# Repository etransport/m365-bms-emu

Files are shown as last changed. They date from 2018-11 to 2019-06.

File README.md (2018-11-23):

# m365-bms-emu
Xiaomi M365 BMS emulator

Main goals of this project: <br>
1 - Emulate communication sequence between ESC and BMS.<br>
2 - Ensure stability and safity over variety of firmwares.<br>

Documentation used in development:<br>
1 - https://electro.club/forum/zamena_yacheek_akb_na_Xiaomi_Mijia_Scooter<br>
2 - https://electro.club/forum/printsipialnaya_shema_drayvera_mk_Xiaomi_M365<br>
3 - https://electro.club/forum/podklyuchenie_alternativnogo_akkumulyatora_k_syaokatu<br>

Hardware used in development:<br>
1 - AVR Attiny CPUS 13/45/85/2313/412/816 in order to determine best price/performance ratio.<br>
2 - AVR Atmega dev boards nano/mini pro/micro pro etc<br>
3 - Seleae logic analyzer <br>

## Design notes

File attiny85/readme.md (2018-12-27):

## ATTINY85 version

**Features:**
- Full duplex communication
- Minimal amount of components needed
- Battery voltage indication
- Auto CRC calculation 
- Customizable battery serial
- ESC overvoltage protection 

**Known bugs:**
- Inaccurate remaining percentage calculation 

Feel free to use or modify as you wish

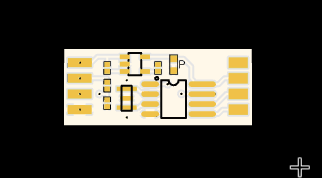
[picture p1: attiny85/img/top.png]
Top view

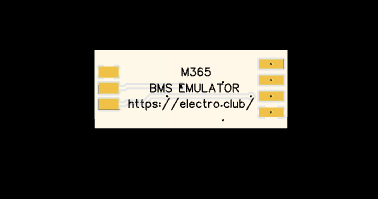
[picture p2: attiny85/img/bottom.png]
Bottom view


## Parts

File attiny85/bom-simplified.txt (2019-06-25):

BOM [M365 BMS EMULATOR V1.1]:
1x B04B-PASK-1 jst header
1x PAP-03V-S jst header
1x PAP-04V-S jst header
7x SPHD-002 copper inserts
1X PCB (see grbl folder)
1x 0402 10Mom 1% resistor
1x 0402 750Kom 1% resistor
1x 0402 10Kom 1% resistor
1x 0603 22uF  5% ceramic capacitor
1x CSTCE 16MHZ ceramic resonator 
1x Attiny85-20SU wsop8 mcu
1x LP2992AIM5 sot23-5 3.3v 250mA low noise regulator

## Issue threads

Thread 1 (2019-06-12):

Connection & pinout

NetBUG, 2019-06-12:
Hi @truesurge!
Thanks for great work on reverse engineering and redesigning the BMS!

Can I ask you to either submit the principal circuit diagram, or to add a PCB image with pinout?
As far as I understand, there are 4 connection pins (3 pins towards main M365 controller and a wire to B10/+42V of the battery), and 6 ICSP pins

I am working on the same circuit for Tiny45 + 1206 elemenes, and promise to publish it ASAP.

truesurge, 2019-06-12:
Hey, @NetBUG.
To start off - I did not redesign bms.
This emulator supposed to work with another bms (cheap/generic chinese), providing m365's main controller with all the info it needs. Basically, it gives user the ability to use another bms, emulator is not a standalone device

Main idea behind the device - read current battery voltage ,  calculate some approximate stats (veeeery inaccurate, as we cant get current consumption) an answer to m365 with correct data.

You can measure battery voltage using BLE connector (4pin), as the power button is connected to B+ through it.
To communicate with esc you need only 2 wires , rx/tx are located on the left side of 3pin.

I will include some pics a bit later

NetBUG, 2019-06-12:
Thanks! I know this is not a BMS, this is a stub replying to Ninebot bus telling battery state, mostly mocking it.

Will wait for pics, will try to find controller pinout

truesurge, 2019-06-23:
> Thanks! I know this is not a BMS, this is a stub replying to Ninebot bus telling battery state, mostly mocking it.
>
> Will wait for pics, will try to find controller pinout

Added image of assembled board in img folder

NetBUG, 2019-06-24:
Awesome! Got your point, I forgot initially about 3.3V LDO.
Here is a circuit I've made based on your design, but the yours is much nicer.
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

truesurge, 2019-06-25:
Yep, looks legit

bugster44, 2019-12-12:
What  values are C1, C2 and C3?

al3x-huang, 2022-06-14:
> Main idea behind the device - read current battery voltage , calculate some approximate stats (veeeery inaccurate, as we cant get current consumption) an answer to m365 with correct data.

Does the original BMS not provide current consumption information?

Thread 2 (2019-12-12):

Any schem?

bugster44, 2019-12-12:
Where i can find schematics? I dont know which resistor where must be.

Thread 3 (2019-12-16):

Hex file and fuse bits for attiny85?

bugster44, 2019-12-16:
Hex file and fuse bits for attiny85?

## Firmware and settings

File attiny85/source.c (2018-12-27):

/* Sketch emulates full duplex transmission of original protocol */
/* Courtesy of https://electro.club/forum/podklyuchenie_alternativnogo_akkumulyatora_k_syaokatu&page=23*/
/* External quartz crystal is a must! See BOM */   

/* ------------------- Pinout -------------------- */ 
/*                   o ________                    */
/*         RESET   --|        |--  +3.3            */
/*  osc1 - PB3     --| attiny |--  PB2 - sense     */
/*  osc2 - PB4     --|   85   |--  PB1 - rx        */
/*         GND     --|________|--  PB0 - tx        */
/*                                                 */
/* ----------------------------------------------- */

#define CAP_HI Capacity&0xFF
#define CAP_LO Capacity>>8
#define REGENERATIVE_CUTOFF 4180
#define ADC_DEPTH 6
#define ADC_SAMPLES 64 /* pow(2,ADC_DEPTH) */

/* Pre-definitions and global variables */
uint16_t Capacity=7800;        /* 16 bytes of capacity, 65536 is max */
uint8_t  VbattOffset=77;       /* VBATT on BLE connector is 0.77v lower than measured on XT30 */
uint8_t  Message[9]={0,0,0,0,0,0,0,0,0}; /* Temp message buffer */
uint16_t ADCBuffer[ADC_SAMPLES];         /* ADC smoothing buffer */
uint8_t  iterator=0;

/* ------------------------------- COMMAND LIST ------------------------------- */
/* Battery serial ESC */
uint8_t cmd1012[]={0x55,0xAA,0x12,0x25,0x01,0x10,'*','E','L','E','C','T','R','O','-','C','L','U','B','*',0x00,0x02};
/* Battery serial MiHome */
uint8_t cmd1014[]={0x55,0xAA,0x14,0x25,0x01,0x10,'*','E','L','E','C','T','R','O','-','C','L','U','B','*',0x00,0x02,CAP_HI,CAP_LO};
/* Charge cycles count */
uint8_t   cmd1B[]={0x55,0xAA,0x06,0x25,0x01,0x1B,0x01,0x00,0x01,0x00};
/* Manufacture date */
uint8_t   cmd20[]={0x55,0xAA,0x08,0x25,0x01,0x20,0x87,0x25,0x00,0x00,0x00,0x00};
/* Battery status ESC */
                           /*LENG/ADDR/READ/CMND/MODE/STAT/CAPACITY /CHARGE   /CURRENT  /VOLTAGE  /TEMP    */
uint8_t   cmd30[]={0x55,0xAA,0x0E,0x25,0x01,0x30,0x01,0x00,0xDE,0xAD,0xBE,0x00,0x10,0x00,0xFA,0xCE,0x2A,0x2B};
/* Battery status MiHome */
                           /*LENG/ADDR/READ/CMND/CAPACITY /CHARGE   /CURRENT  /VOLTAGE  /TEMP    */
uint8_t   cmd31[]={0x55,0xAA,0x0C,0x25,0x01,0x31,0xDE,0xAD,0xBE,0x00,0x10,0x00,0xFA,0xCE,0x2A,0x2B};
/* Battery ping */
uint8_t   cmd3B[]={0x55,0xAA,0x04,0x25,0x01,0x3B,0x62,0x00};
/* Battery cell voltages */
uint8_t  cmd40[]={0x55,0xAA,0x20,0x25,0x01,0x40,0xCE,0xCE,0xCE,0xCE,0xCE,0xCE,0xCE,0xCE,0xCE,0xCE,0xCE,0xCE,0xCE,0xCE,0xCE,0xCE,0xCE,0xCE,0xCE,0xCE,0xCE,0xCE,0xCE,0xCE,0xCE,0xCE,0xCE,0xCE,0xCE,0xCE};
/* ----------------------------------------------------------------------------- */

uint16_t NormalizeBridge(uint16_t voltage)
{
  /*    -[10MOm]-|-[750kOm]-
   * 5v calibrated is 74 after division.
   * So, to get approx voltage, divide by 15    */
  /* Drop 4 least significant bits */
  uint16_t dropped=voltage&0x3F0;
  return (uint16_t)(((float)dropped/15.0)*100.0)-VbattOffset; 
}

void setup()  
{
  pinMode(A1,INPUT);
  Serial.begin(115200);
  for(uint8_t i=0;i<ADC_SAMPLES;i++)
  	ADCBuffer[i]=4100;
}

uint8_t VoltageToPercent(uint16_t voltage)
{
  /* Drop last digit */
  voltage=voltage/10;
  voltage=voltage*10;
  /* Convert, using approximate discharge curves */
  float vcell=float(((float)voltage)/1000.0);
  uint8_t percent=((45.078)*(vcell*vcell)-238.258*(vcell)+312.0);
  if(percent<0)   return 0;
  if(percent>100) return 100;
  return percent;
  /* ------------------------------- */
}

void UpdateStats()
{
  /* Get sample */
  uint16_t Sample=NormalizeBridge(analogRead(A1));  
  /* -------------------------------- */
  
  /* Overvoltage protection, ! EXPERIMENTAL ! */
  if(Sample>REGENERATIVE_CUTOFF) cmd30[7]=0x02; /* Bit 9 supposed to be overvoltage feedback */
  else cmd30[7]=0x00;
  /* ---------- */
  
  /* Average */
  ADCBuffer[iterator]=(uint16_t)Sample;
  iterator=(iterator==ADC_SAMPLES-1)?0:iterator+1;
  uint32_t Average=0;
  for(uint8_t i=0;i<ADC_SAMPLES;i++)
  	Average+=ADCBuffer[i];
  /* ----------------- */
 
  uint16_t BatteryVoltage=(uint16_t)(Average>>ADC_DEPTH);
  
  /* Update battery voltage */
  cmd30[14]=cmd31[12]=BatteryVoltage&0xFF;
  cmd30[15]=cmd31[13]=BatteryVoltage>>8;


  /* Update remaining power */
  uint8_t  RemainingPower=VoltageToPercent(BatteryVoltage);
  cmd30[10]=cmd31[8]=RemainingPower;
  /* ---------- */
  
  /* Update remaining capacity */
  uint16_t RemainingCapacity=(float)(Capacity)*((float)RemainingPower/100.0);
  cmd30[8]=cmd31[6]=RemainingCapacity&0xFF;
  cmd30[9]=cmd31[7]=RemainingCapacity>>8;
  /* ------------------ */
}

void UpdateCells()
{

  /* Get battery voltage */
  uint16_t BatteryVoltage=NormalizeBridge(analogRead(A1));
  /* ----------------- */
  
  /* Update each cell */ 
  for(uint8_t i=6;i<36;i+=2)
  {
    cmd40[i]=BatteryVoltage&0xFF;;
    cmd40[i+1]=BatteryVoltage>>8;
  }
  /* ---------------- */
}

void SendCMD(uint8_t *cmd)
{ 
  /* Calc CRC */
  uint16_t crc=0xFFFF;
  for(int i=2;i<cmd[2]+4;i++)
  crc-=cmd[i];
  /* ---------- */
  
  /* Prepare bytes before transmit to maintain bitrate, these values have to be calculated ! before ! transmission */
  uint8_t crc_high=crc&0xFF;
  uint8_t crc_low=crc>>8;
  /* ---------- */

  /* Drop CMD into Serial */
  noInterrupts();
  Serial.write(cmd,cmd[2]+4);
  Serial.write(crc_high);
  Serial.write(crc_low);
  interrupts();
  /* -------------------- */
}

void loop() 
{ 
 if(Serial.available()>=9)
 {
   if(Serial.peek()==0x55)
  {
   for(uint8_t i=0;i<9;i++)
    Message[i]=Serial.read();
     switch(Message[5])
      {
        case (0x10):{ if(Message[6]==0x10) SendCMD(cmd1012); else SendCMD(cmd1014);}  break;
        case (0x1B):{ SendCMD(cmd1B);} break;
        case (0x20):{ SendCMD(cmd20);} break;
        case (0x30):{ UpdateStats(); SendCMD(cmd30);} break;
        case (0x31):{ UpdateStats(); SendCMD(cmd31);} break;
        case (0x3B):{ SendCMD(cmd3B);} break;
        case (0x40):{ UpdateCells(); SendCMD(cmd40);} break;
        default: break;
      };
    }
    else Serial.read();
 }
}

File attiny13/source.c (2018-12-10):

/* Following sketch is minimalistic approach. No battery percentage is transmitted, no power usage logging */
/* Scooter moves on its own and does not show any errors                                                   */
/* External active quartz is necesarry, internal RC is too unstable for soft 115200 baudrate               */
/* Courtesy of https://electro.club/forum/zamena_yacheek_akb_na_Xiaomi_Mijia_Scooter                       */
/* Proof of concept only!                                                                                  */

#define F_CPU 9600000 
/*
9.6 mHz internal RC-oscillator is used. This stuff is extremely unstable and not to be recommended/
*/

#include <avr/io.h>
#include <util/delay.h>
#include <avr/pgmspace.h>
const char magic[]PROGMEM ={0x55,0xAA,0x0E,0x25,0x01,0x30,0x01,0x00,0x00,0x00,0x00,0x00,0x00,0x00,0xE1,0x00,0x28,0x28,0x91,0xFE};

/*
55AA0E2501300100000000000000E100282891FE works well with 1.3.0-1.3.4, untested with higher firmwares.
Mihome battery info stays blank, though kickscooter does not beep and achieves full speed.
No overvoltage protection is hardcoded!
*/

#define SOFT_TX_PIN (1<<PB1) // PB1 is concidered as TX output
#define SOFT_TX_PORT PORTB
#define SOFT_TX_DDR DDRB
void uart_tx_init ()
{
  TCCR0A = 1 << WGM01;    // Compare mode
  TCCR0B = 1 << CS00;   // Prescaler 1
  SOFT_TX_PORT |= SOFT_TX_PIN;
  SOFT_TX_DDR |= SOFT_TX_PIN;
  OCR0A = 75;     //115200 baudrate at prescaler 1, ~83-84us baud period in real world, according to logic analyzer
}

//Bitbang UART
void uart_send_byte (unsigned char data)
{
  unsigned char i;
  TCCR0B = 0;
  TCNT0 = 0;
  TIFR0 |= 1 << OCF0A;
  TCCR0B |= (1 << CS00);
  TIFR0 |= 1 << OCF0A;
  SOFT_TX_PORT &= ~SOFT_TX_PIN;
  while (!(TIFR0 & (1 << OCF0A)));
  TIFR0 |= 1 << OCF0A;
  for (i = 0; i < 8; i++)
  {
    if (data & 1)
      SOFT_TX_PORT |= SOFT_TX_PIN;
    else
      SOFT_TX_PORT &= ~SOFT_TX_PIN;
    data >>= 1;
    while (!(TIFR0 & (1 << OCF0A)));
    TIFR0 |= 1 << OCF0A;
  }
  SOFT_TX_PORT |= SOFT_TX_PIN;
  while (!(TIFR0 & (1 << OCF0A)));
  TIFR0 |= 1 << OCF0A;
}

void setup()
{
    uart_tx_init (); 
}

void loop()
{
    for(byte i=0;i<20;i++)
      uart_send_byte(magic[i]);
    _delay_ms(1000);
     
}

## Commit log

2018-12-27 Proof of concept [UNSTABLE]
    [source.c]
2019-06-23 Added look of finished board
